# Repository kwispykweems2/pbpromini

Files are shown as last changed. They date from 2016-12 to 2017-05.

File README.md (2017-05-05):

# pbpromini
Arduino 328PB Pro Mini - What the next UNO needs.

This is an Eagle board package for the PB Pro Mini.  This is very much based on, and mostly pin-compatible with the Arduino Pro Mini 5V/16MHz from Sparkfun, but uses the Atmega328PB.

Notable, not-so-minor improvements for the 'B' version:
- 2 UARTs
- 2 I2Cs (TWI)
- 2 SPI
- Qtouch
- 5 Timers (with OC, IC, and PWM)

Further info and writeup: http://jwillylinux.blogspot.com/2016/12/pb-pro-mini.html

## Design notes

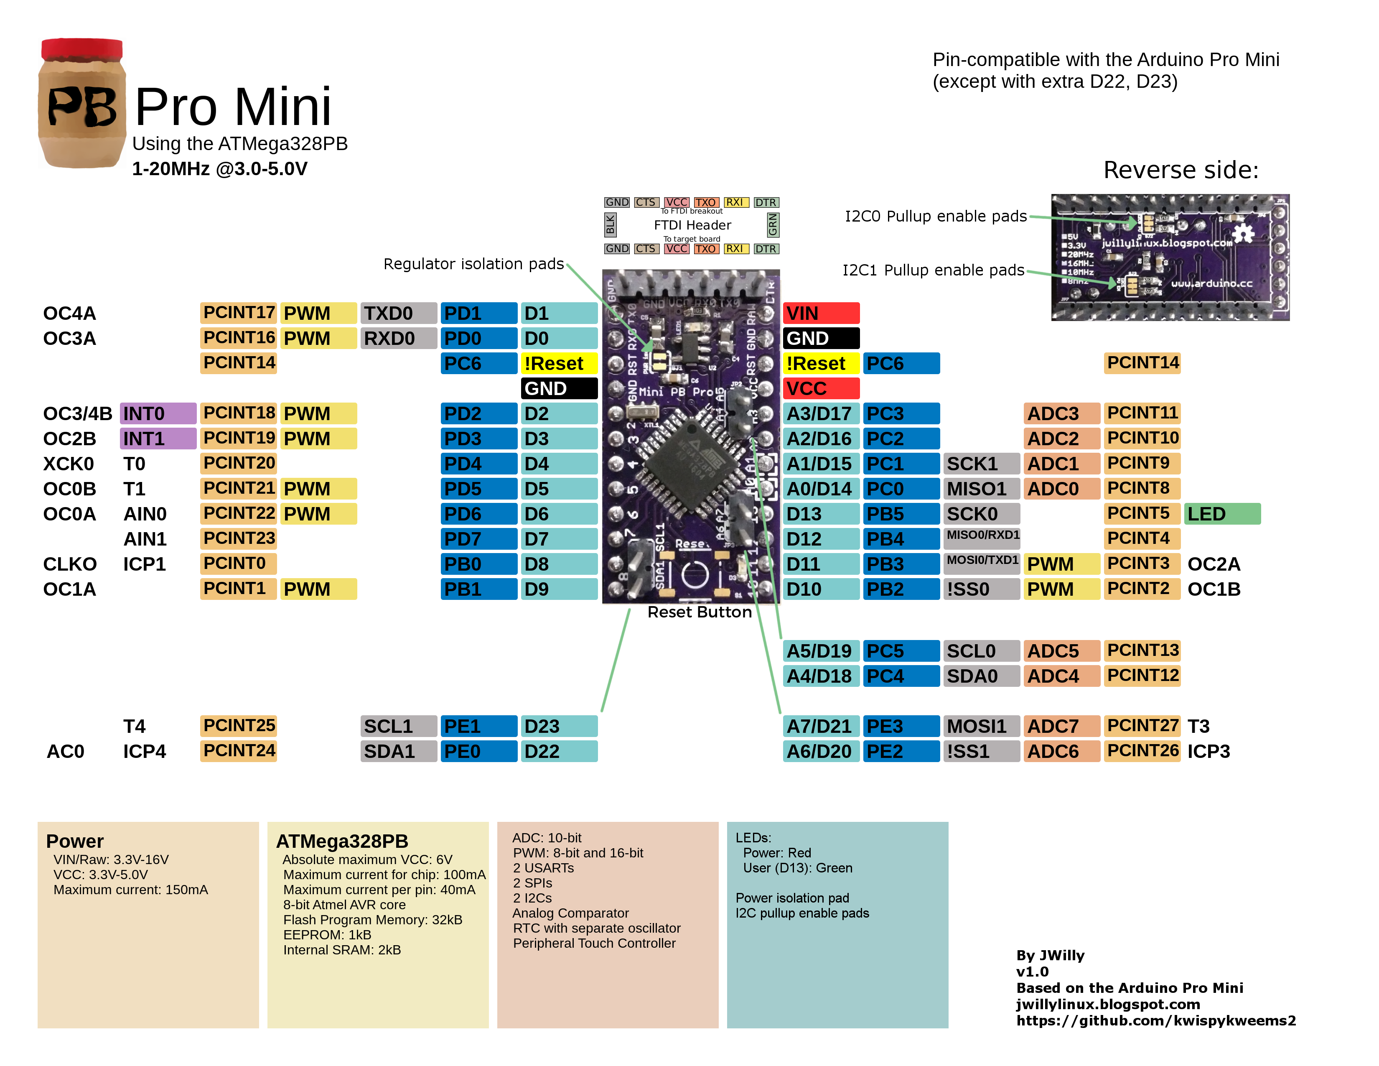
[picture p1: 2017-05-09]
PBProMini.png

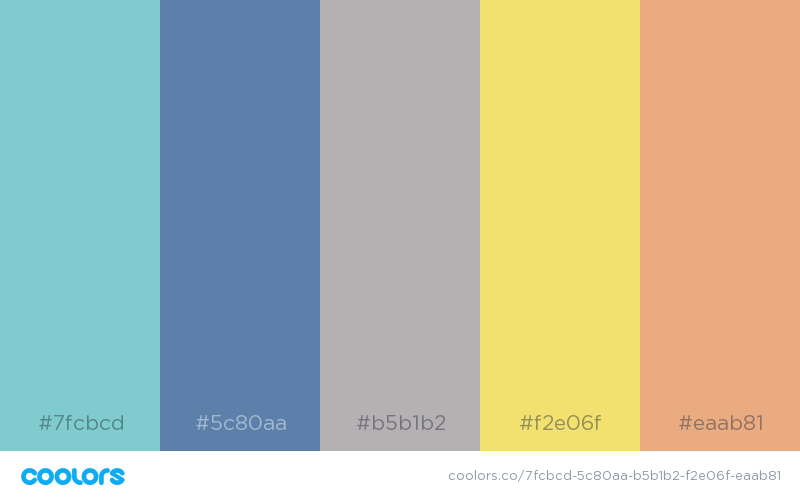
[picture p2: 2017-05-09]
color_palette2.png

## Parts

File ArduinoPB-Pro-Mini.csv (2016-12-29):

Qty | Value | Device | Package | Parts | Description
2 |  | JUMPER-PAD-3-NC_BY_TRACE | PAD-JUMPER-3-3OF3_NC_BY_TRACE_YES_SILK_FULL_BOX | SJ2, SJ3
1 |  | SOLDERJUMPERTRACE | SJ_2S-TRACE | SJ1 | Solder Jumper
4 | 0.1uF | C-USC0603 | C0603 | C1, C2, C3, C6 | CAPACITOR, American symbol
3 | 10k | R-US_R0603 | R0603 | R1, R2, R7 | RESISTOR, American symbol
2 | 10uF | C-USC0805 | C0805 | C4, C5 | CAPACITOR, American symbol
4 | 2.7k | R-US_R0603 | R0603 | R3, R4, R5, R6 | RESISTOR, American symbol
1 | 8/16/20MHz | RESONATOR1:1 | RESONATOR-SMD-1:1 | XTL1 | Resonator
1 | ATMEGA328PB-A | ATMEGA328PB-A | TQFP32-08 | U1 | MICROCONTROLLER
2 | CON12C | CON12C | 1X12C | JP6, JP7 | 8-pin Thru-hole Header
3 | CON2C | CON2C | 1X2C | JP2, JP3, JP4
1 | FRAME-LETTER | FRAME-LETTER | CREATIVE_COMMONS | FRAME1 | Schematic Frame
1 | FTDI Basic | ARDUINO_SERIAL_PROGRAM | 1X6C | JP1
1 | Green | LED | 0603-LED-ALT1 | D3 | LEDs
1 | MIC5205 | V_REG_LDOSMD | SOT23-5 | U2 | Voltage Regulator LDO
1 | OSHW-LOGOS | OSHW-LOGOS | OSHW-LOGO-S | U$3 | Open Source Hardware Logo This logo indicates the piece of hardware it is found on incorporates a OSHW license and/or adheres to the definition of open source hardware found here: http://freedomdefined.org/OSHW
1 | Red | LED | 0603-LED-ALT1 | LED1 | LEDs
1 | Reset | SWITCH-MOMENTARY-2SMD-ALT01 | TACTILE-SWITCH-SMD-ALT01 | S1 | Various NO switches- pushbuttons, reed, etc

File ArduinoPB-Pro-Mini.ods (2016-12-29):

Qty | Value | Device | Package | Parts | Description
4 | 0.1uF | C-USC0603 | C0603 | C1, C2, C3, C6 | CAPACITOR, American symbol
2 | 10uF | C-USC0805 | C0805 | C4, C5 | CAPACITOR, American symbol
1 | Green | LED | 0603-LED-ALT1 | D3 | LEDs
1 | FRAME-LETTER | FRAME-LETTER | CREATIVE_COMMONS | FRAME1 | Schematic Frame
1 | FTDI Basic | ARDUINO_SERIAL_PROGRAM | 1X6C | JP1
3 | CON2C | CON2C | 1X2C | JP2, JP3, JP4
2 | CON12C | CON12C | 1X12C | JP6, JP7 | 8-pin Thru-hole Header
1 | Red | LED | 0603-LED-ALT1 | LED1 | LEDs
3 | 10k | R-US_R0603 | R0603 | R1, R2, R7 | RESISTOR, American symbol
4 | 2.7k | R-US_R0603 | R0603 | R3, R4, R5, R6 | RESISTOR, American symbol
1 | Reset | SWITCH-MOMENTARY-2SMD-ALT01 | TACTILE-SWITCH-SMD-ALT01 | S1 | Various NO switches- pushbuttons, reed, etc
1 |  | SOLDERJUMPERTRACE | SJ_2S-TRACE | SJ1 | Solder Jumper
2 |  | JUMPER-PAD-3-NC_BY_TRACE | PAD-JUMPER-3-3OF3_NC_BY_TRACE_YES_SILK_FULL_BOX | SJ2, SJ3
1 | OSHW-LOGOS | OSHW-LOGOS | OSHW-LOGO-S | U$3 | Open Source Hardware Logo This logo indicates the piece of hardware it is found on incorporates a OSHW license and/or adheres to the definition of open source hardware found here: http://freedomdefined.org/OSHW
1 | ATMEGA328PB-A | ATMEGA328PB-A | TQFP32-08 | U1 | MICROCONTROLLER
1 | MIC5205 | V_REG_LDOSMD | SOT23-5 | U2 | Voltage Regulator LDO
1 | 8/16/20MHz | RESONATOR1:1 | RESONATOR-SMD-1:1 | XTL1 | Resonator

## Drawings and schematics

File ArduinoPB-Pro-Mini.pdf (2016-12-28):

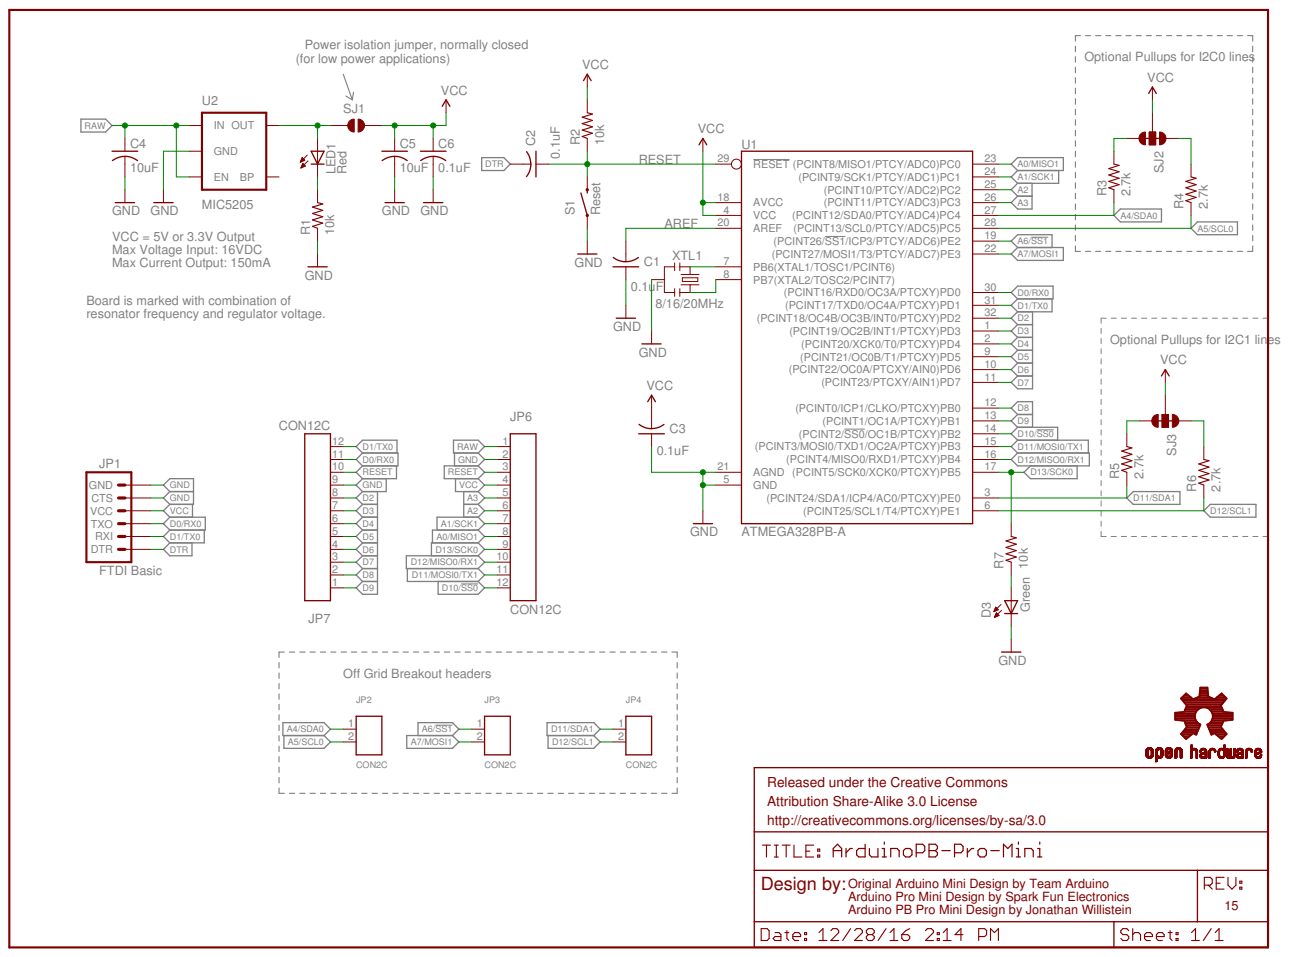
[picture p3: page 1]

Power isolation jumper, normally closed
(for low power applications)

Optional Pullups for I2C0 lines

Board is marked with combination of resonator frequency and regulator voltage.

Optional Pullups for I2C1 lines

Off Grid Breakout headers

Released under the Creative Commons
Attribution Share-Alike 3.0 License
http://creativecommons.org/licenses/by-sa/3.0

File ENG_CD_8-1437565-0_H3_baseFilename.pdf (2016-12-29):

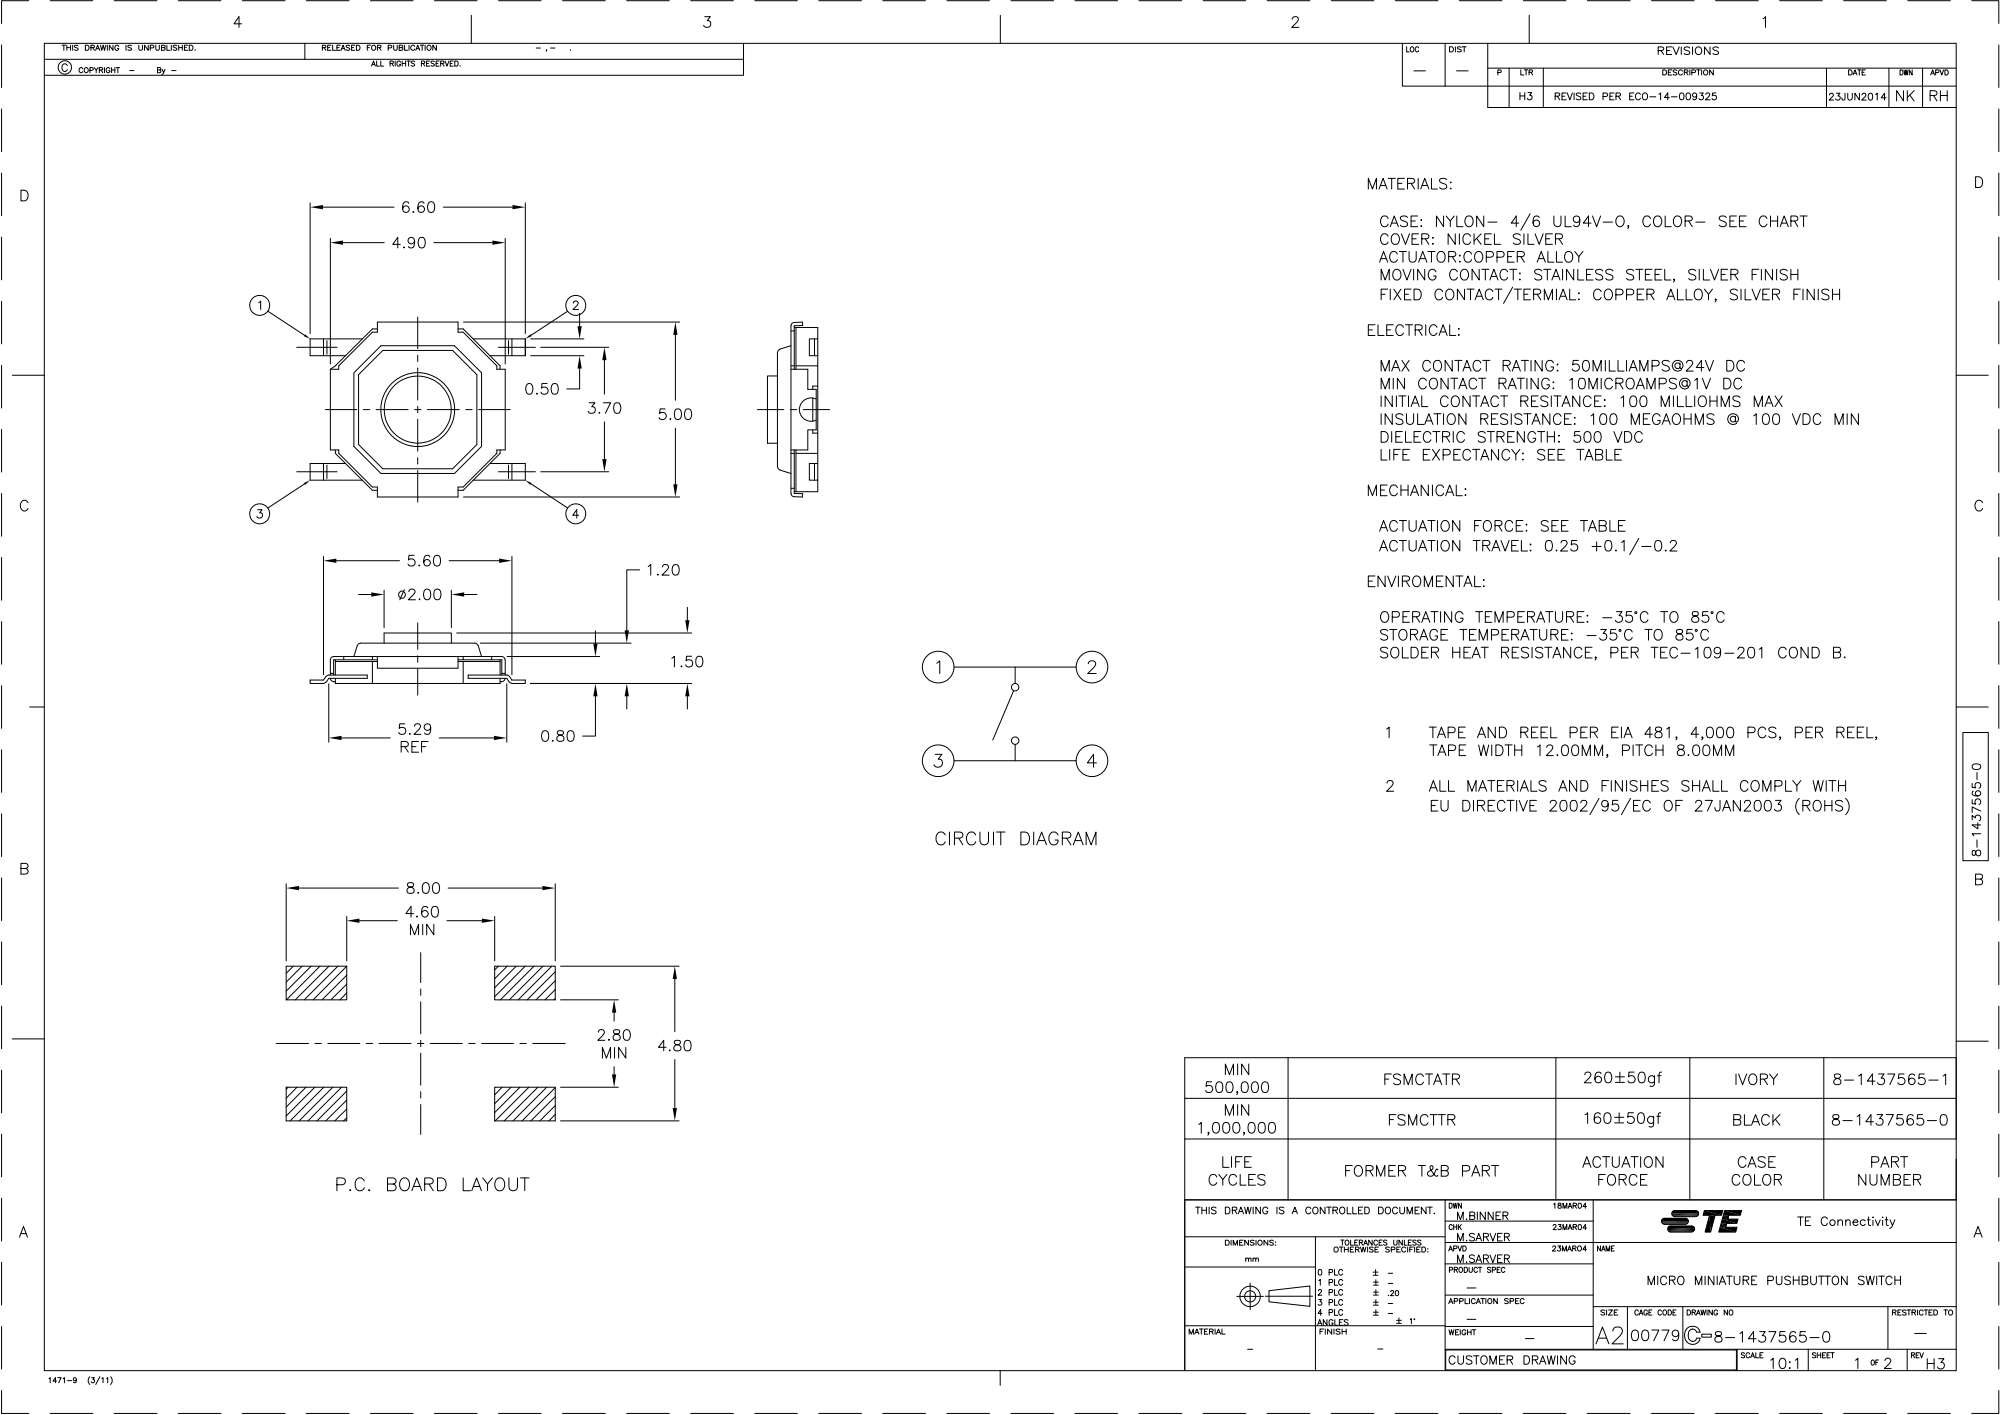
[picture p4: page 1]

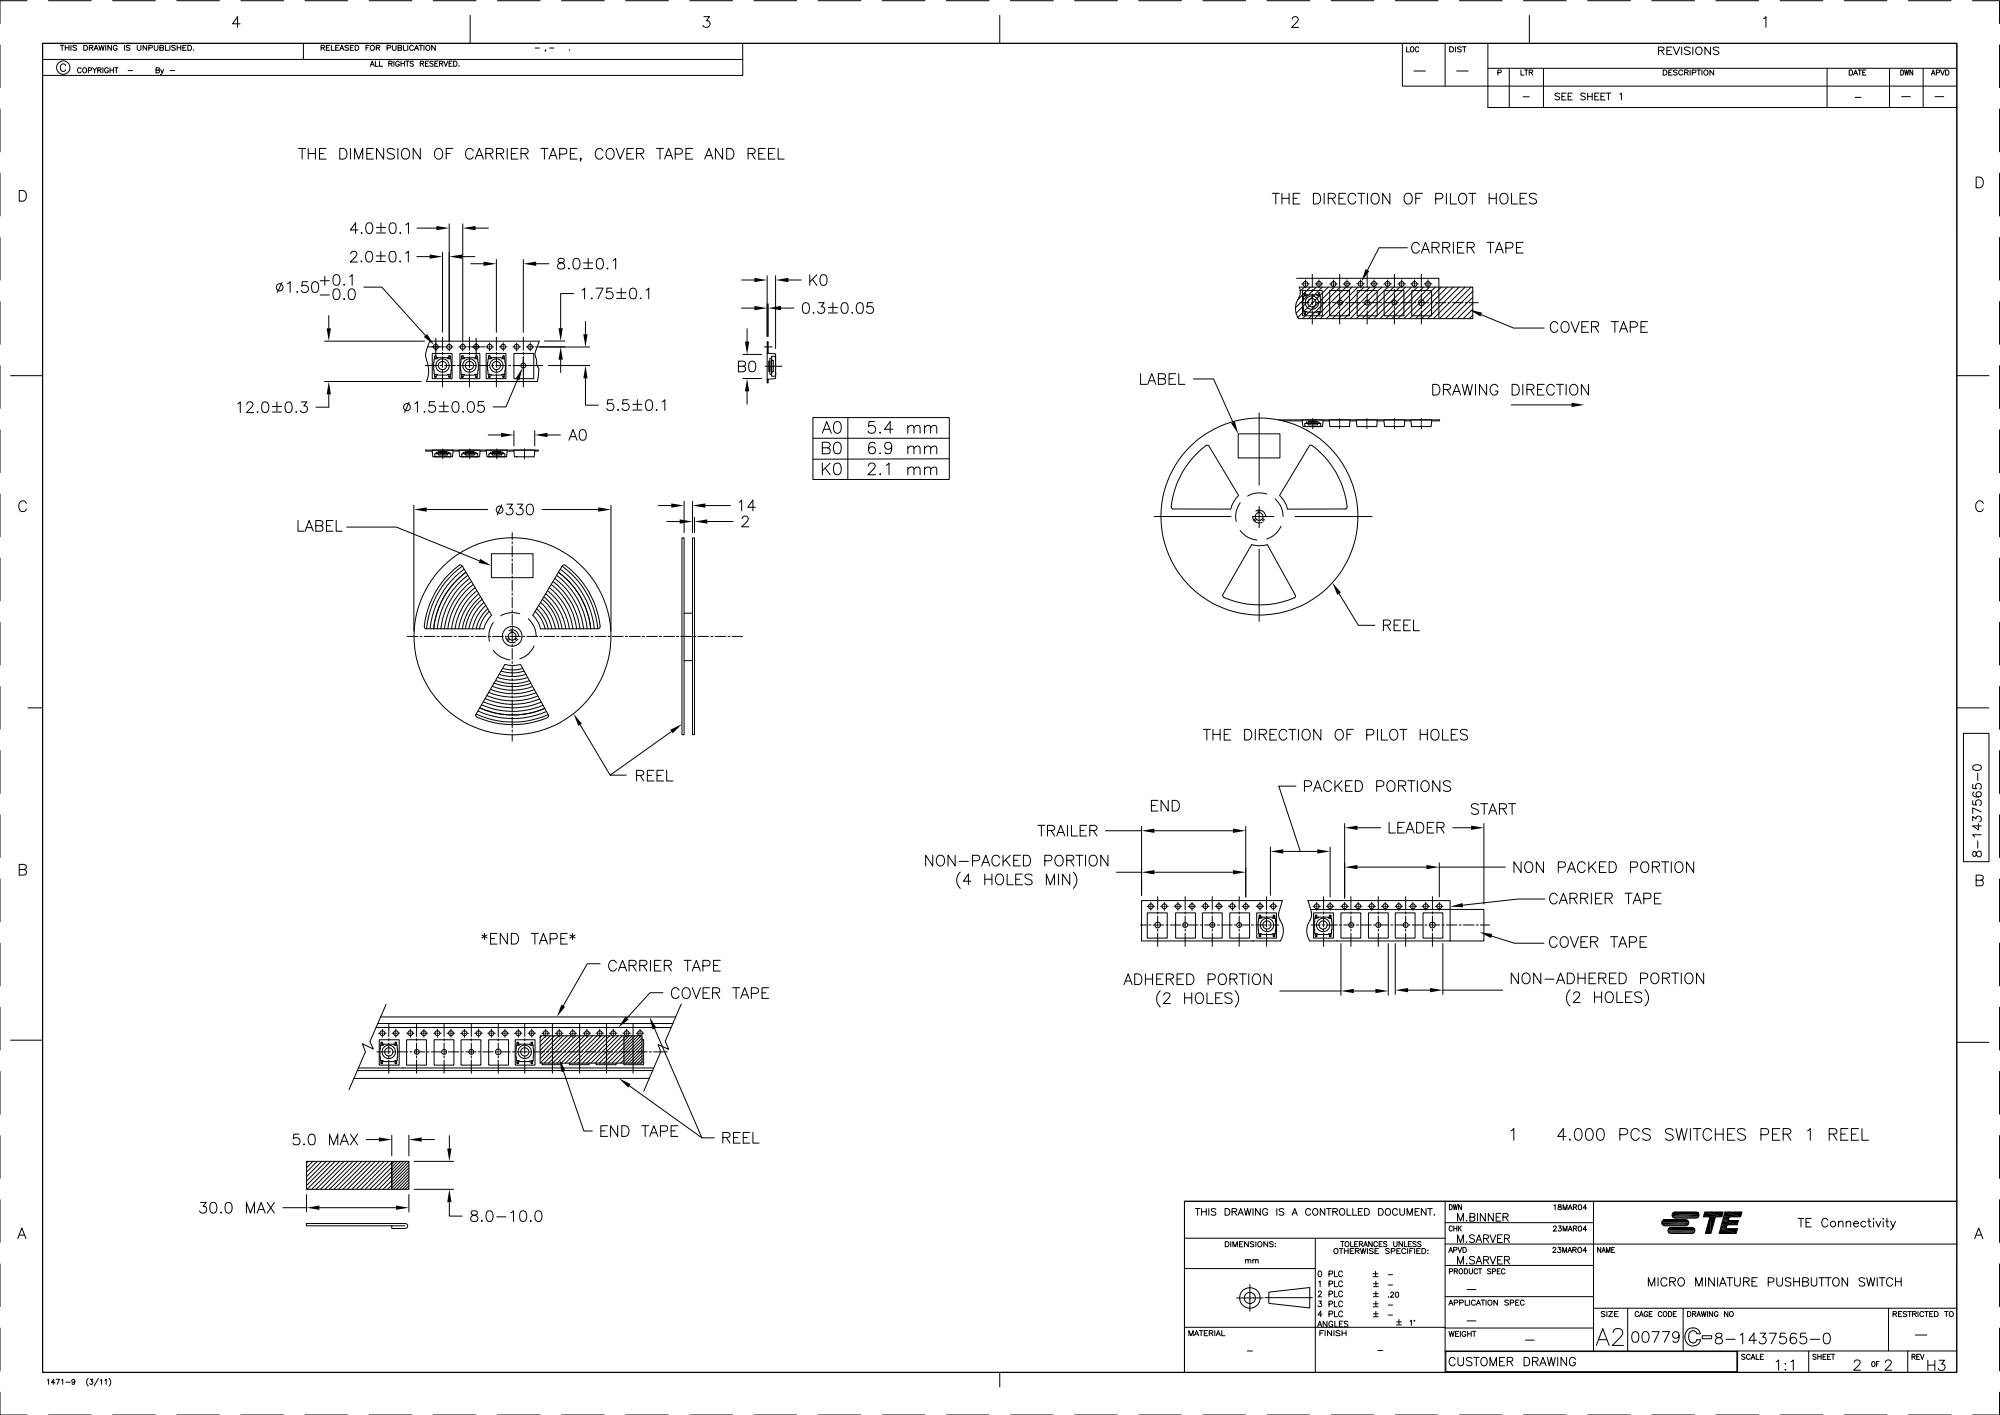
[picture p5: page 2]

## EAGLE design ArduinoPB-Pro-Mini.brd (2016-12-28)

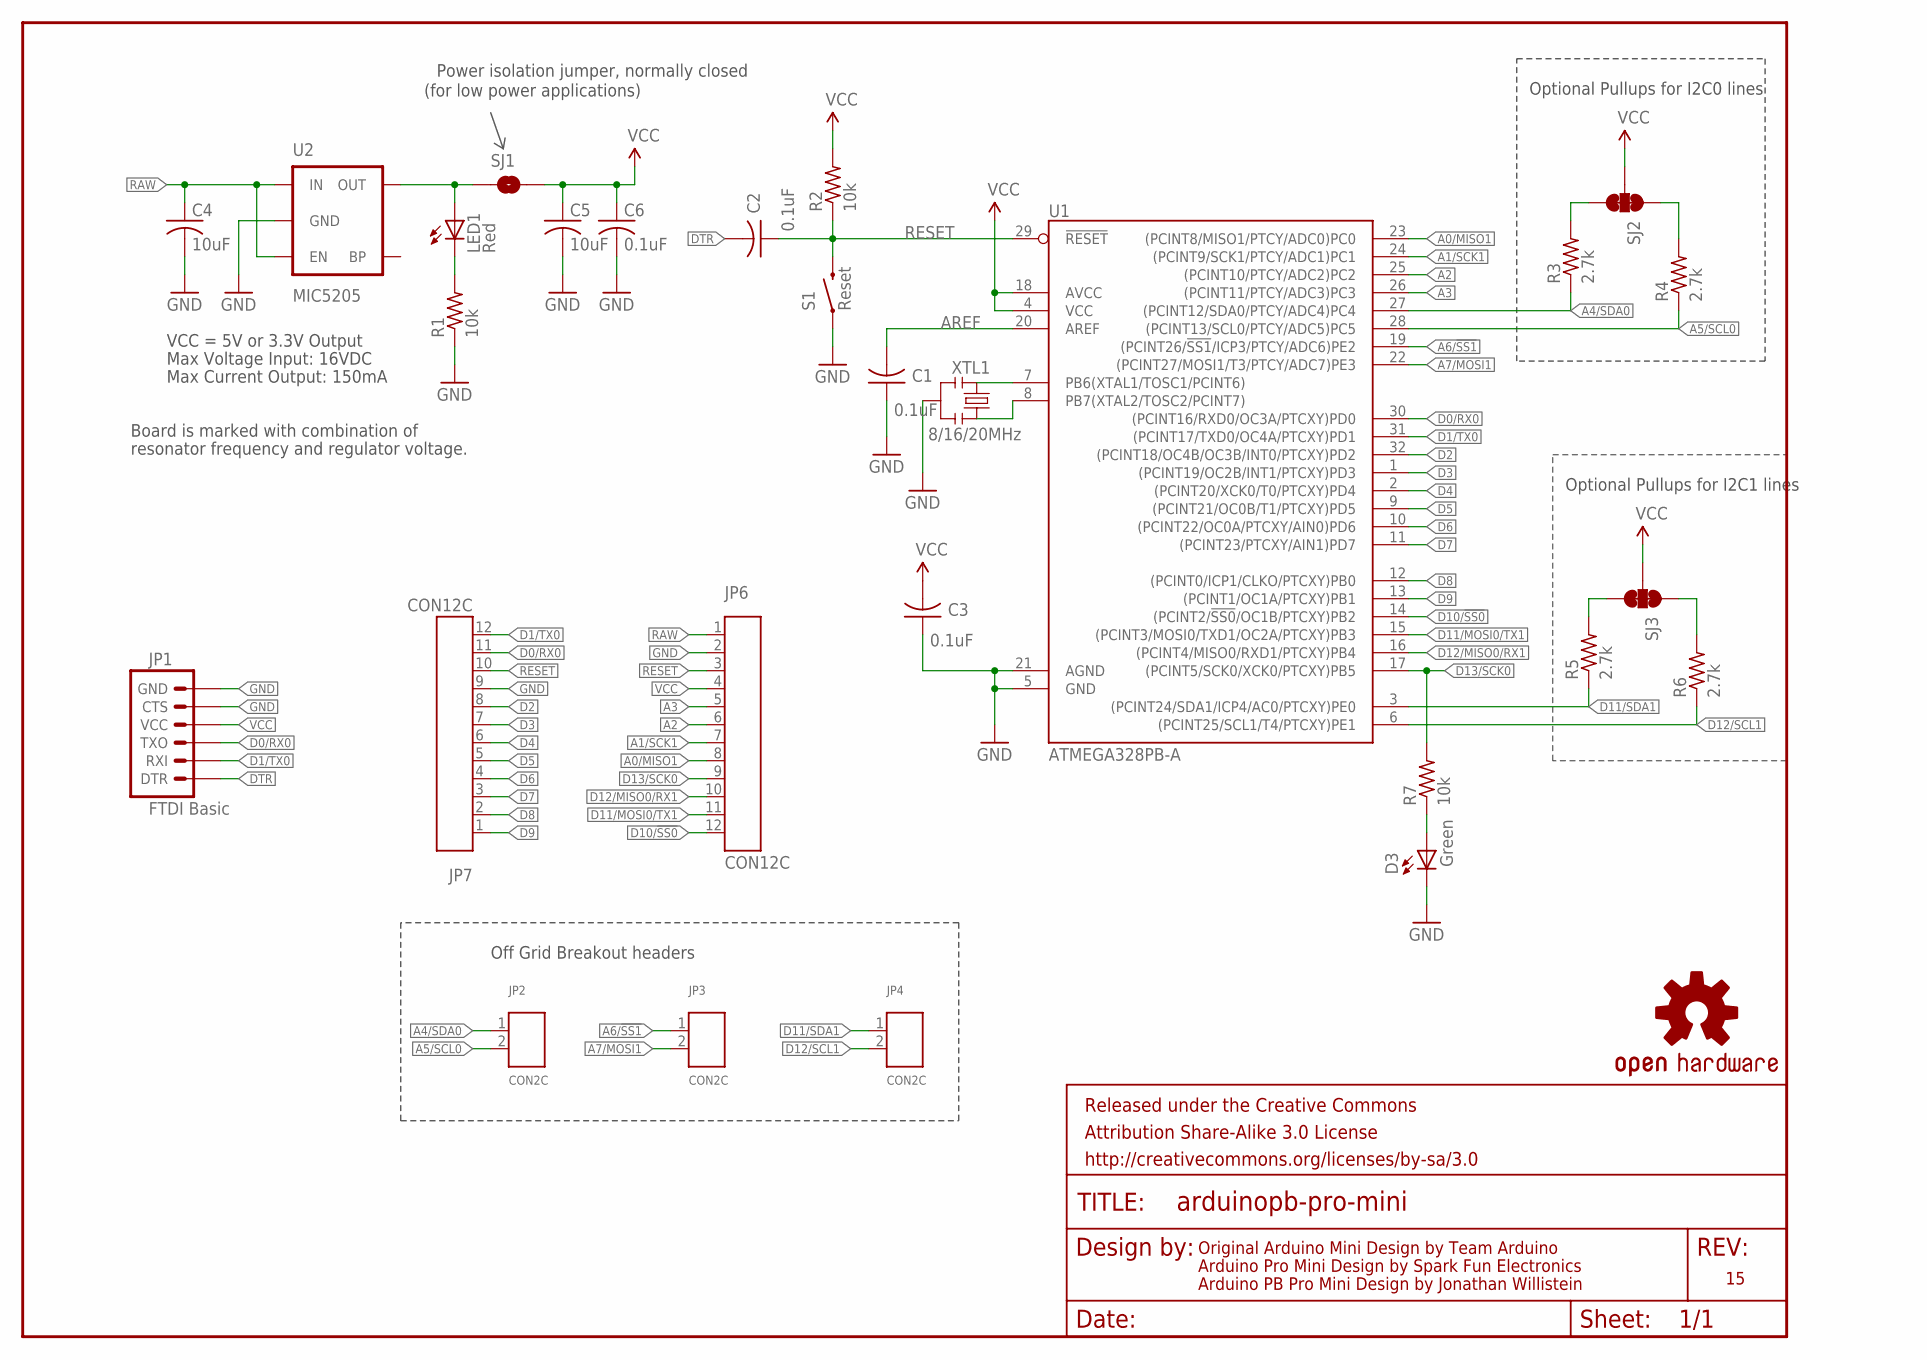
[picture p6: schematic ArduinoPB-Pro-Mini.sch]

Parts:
C1, C2, C3, C6: 0.1uF; C0603
C4, C5: 10uF; C0805
D3: Green; 0603-LED-ALT1
FRAME1: FRAME-LETTER; CREATIVE_COMMONS
JP1: FTDI Basic; 1X6C
JP2, JP3, JP4: CON2C; 1X2C
JP6, JP7: CON12C; 1X12C
LED1: Red; 0603-LED-ALT1
R1, R2, R7: 10k; R0603
R3, R4, R5, R6: 2.7k; R0603
S1: Reset; TACTILE-SWITCH-SMD-ALT01
SJ1: SOLDERJUMPERTRACE; SJ_2S-TRACE
SJ2, SJ3: JUMPER-PAD-3-NC_BY_TRACE; PAD-JUMPER-3-3OF3_NC_BY_TRACE_YES_SILK_FULL_BOX
U1: ATMEGA328PB-A; TQFP32-08
U2: MIC5205; SOT23-5
U$3: OSHW-LOGOS; OSHW-LOGO-S
XTL1: 8/16/20MHz; RESONATOR-SMD-1:1

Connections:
A0/MISO1: JP6.8, U1.23 ((PCINT8/MISO1/PTCY/ADC0)PC0)
A1/SCK1: JP6.7, U1.24 ((PCINT9/SCK1/PTCY/ADC1)PC1)
A2: JP6.6, U1.25 ((PCINT10/PTCY/ADC2)PC2)
A3: JP6.5, U1.26 ((PCINT11/PTCY/ADC3)PC3)
A4/SDA0: JP2.1, R3.1, U1.27 ((PCINT12/SDA0/PTCY/ADC4)PC4)
A5/SCL0: JP2.2, R4.1, U1.28 ((PCINT13/SCL0/PTCY/ADC5)PC5)
A6/!SS1: JP3.1, U1.19 ((PCINT26/!SS1!/ICP3/PTCY/ADC6)PE2)
A7/MOSI1: JP3.2, U1.22 ((PCINT27/MOSI1/T3/PTCY/ADC7)PE3)
AREF: C1.2, U1.20 (AREF)
D0/RX0: JP1.3 (TXO), JP7.11, U1.30 ((PCINT16/RXD0/OC3A/PTCXY)PD0)
D1/TX0: JP1.2 (RXI), JP7.12, U1.31 ((PCINT17/TXD0/OC4A/PTCXY)PD1)
D2: JP7.8, U1.32 ((PCINT18/OC4B/OC3B/INT0/PTCXY)PD2)
D3: JP7.7, U1.1 ((PCINT19/OC2B/INT1/PTCXY)PD3)
D4: JP7.6, U1.2 ((PCINT20/XCK0/T0/PTCXY)PD4)
D5: JP7.5, U1.9 ((PCINT21/OC0B/T1/PTCXY)PD5)
D6: JP7.4, U1.10 ((PCINT22/OC0A/PTCXY/AIN0)PD6)
D7: JP7.3, U1.11 ((PCINT23/PTCXY/AIN1)PD7)
D8: JP7.2, U1.12 ((PCINT0/ICP1/CLKO/PTCXY)PB0)
D9: JP7.1, U1.13 ((PCINT1/OC1A/PTCXY)PB1)
D10/!SS0: JP6.12, U1.14 ((PCINT2/!SS0!/OC1B/PTCXY)PB2)
D11/MOSI0/TX1: JP6.11, U1.15 ((PCINT3/MOSI0/TXD1/OC2A/PTCXY)PB3)
D11/SDA1: JP4.1, R5.1, U1.3 ((PCINT24/SDA1/ICP4/AC0/PTCXY)PE0)
D12/MISO0/RX1: JP6.10, U1.16 ((PCINT4/MISO0/RXD1/PTCXY)PB4)
D12/SCL1: JP4.2, R6.1, U1.6 ((PCINT25/SCL1/T4/PTCXY)PE1)
D13/SCK0: JP6.9, R7.2, U1.17 ((PCINT5/SCK0/XCK0/PTCXY)PB5)
DTR: C2.2, JP1.1 (DTR)
GND: C1.1, C3.1, C4.2, C5.2, C6.2, D3.C, JP1.5 (CTS), JP1.6 (GND), JP6.2, JP7.9, R1.1, S1.1, S1.2 (1), U1.5 (GND), U1.21 (AGND), U2.2 (GND), XTL1.2
unnamed: U1.7 (PB6(XTAL1/TOSC1/PCINT6)), XTL1.1
unnamed: U1.8 (PB7(XTAL2/TOSC2/PCINT7)), XTL1.3
unnamed: LED1.C, R1.2
unnamed: R3.2, SJ2.3
unnamed: R4.2, SJ2.1
unnamed: D3.A, R7.1
unnamed: R5.2, SJ3.3
unnamed: R6.2, SJ3.1
RAW: C4.1, JP6.1, U2.1 (IN), U2.3 (EN)
RESET: C2.1, JP6.3, JP7.10, R2.1, S1.3 (2), S1.4 (2), U1.29 (!RESET!)
VCC: C3.2, C5.1, C6.1, JP1.4 (VCC), JP6.4, R2.2, SJ1.2, SJ2.2, SJ3.2, U1.4 (VCC), U1.18 (AVCC)
VOUT: LED1.A, SJ1.1, U2.5 (OUT)

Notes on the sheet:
Original Arduino Mini Design by Team Arduino
Arduino Pro Mini Design by Spark Fun Electronics
Max Voltage Input: 16VDC
Max Current Output: 150mA
Board is marked with combination of
resonator frequency and regulator voltage.
VCC = 5V or 3.3V Output
Optional Pullups for I2C0 lines
Off Grid Breakout headers
Power isolation jumper, normally closed
(for low power applications)
Arduino PB Pro Mini Design by Jonathan Willistein
Optional Pullups for I2C1 lines

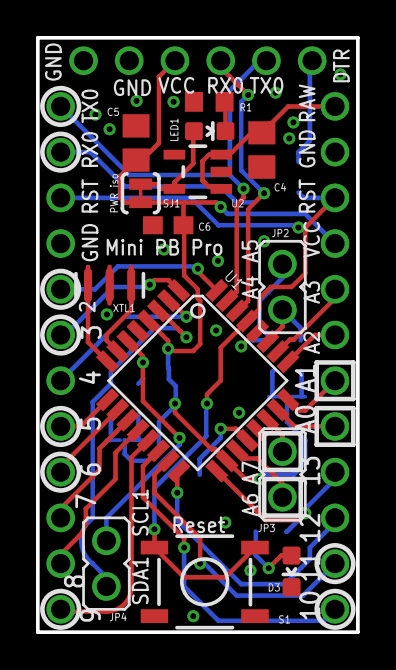
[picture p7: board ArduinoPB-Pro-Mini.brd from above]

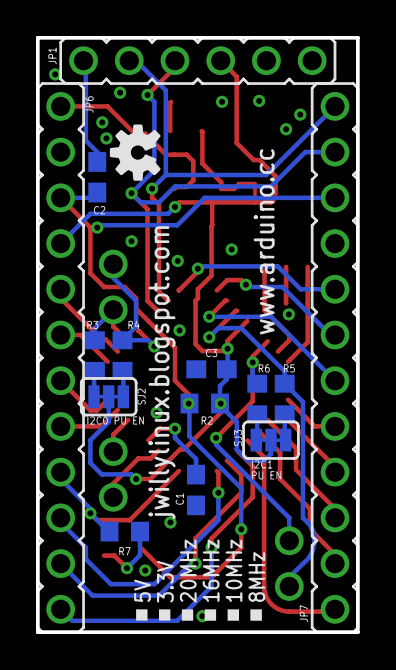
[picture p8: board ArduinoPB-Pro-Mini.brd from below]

Board: 2 copper layers, 17.8 x 33.0 mm, 30 parts (15 on the bottom side), 39 nets.

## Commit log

2016-12-28 Initial design upload of Eagle files and schematic
    [ArduinoPB-Pro-Mini.brd, ArduinoPB-Pro-Mini.sch]
2016-12-29 Finish BoM, upload datasheets.
    [ArduinoPB-Pro-Mini.csv, ArduinoPB-Pro-Mini.ods]

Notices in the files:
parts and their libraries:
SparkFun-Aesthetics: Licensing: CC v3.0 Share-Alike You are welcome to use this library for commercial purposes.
